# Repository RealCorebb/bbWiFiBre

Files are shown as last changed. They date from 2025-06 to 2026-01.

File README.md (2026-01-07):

# bbWiFibre [English](https://github.com/RealCorebb/bbWiFiBre/blob/main/README_EN.md "English")

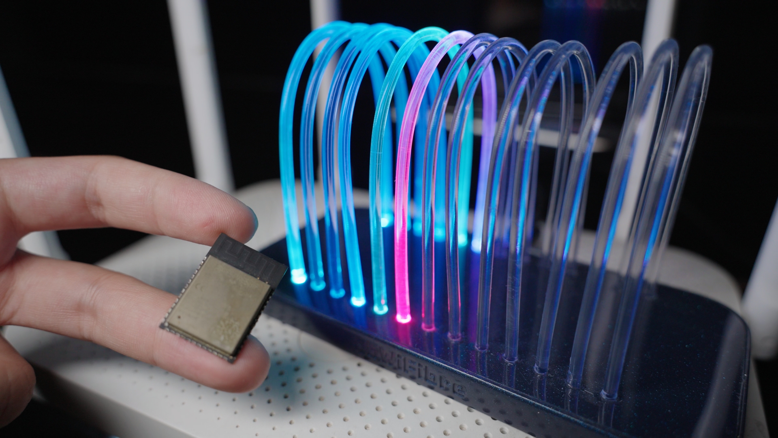
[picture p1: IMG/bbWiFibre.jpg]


## 能看见 WiFi 信号的氛围灯

电脑、路由器网口上闪烁的小灯大家都不陌生，看上去像是在乱闪，没人太在意。那无线的 Wi-Fi 网络，能不能也做一个这种“信号灯”呢？于是我 DIY 了一个 Wi-Fi 嗅探器，并将捕捉到的数据通过代码和算法进行可视化，变成了一个可以实时探测 Wi-Fi 信号的氛围灯。

😄[爱发电](https://afdian.com/a/kuruibb "爱发电") (已更新此图文教程）  
🧵[Threads](https://www.threads.net/@coreoobb "@coreoobb") @coreoobb  
🐧QQ 群（仅供交流，人满请加Discord）：647186542  
😈Discord 频道：[加入](https://discord.gg/gvbcCtdQrk "加入")   
▶️ 本期视频(Video): [Youtube](https://youtu.be/fgVX8Ttq5zc "Youtube") | [ Bilibili](https://www.bilibili.com/video/BV1DB8xz7E7a " Bilibili")

# 禁止搬运到 Gitee

Designed By Corebb With Love From bbRealm!

# 目录结构：

**Arduino** Arduino 主程序，烧录到 ESP32 中  
**PCB** PCB 原理图、Gerber 制板文件、BOM  
**CAD** 3D模型、DXF切割图纸  
**test** Arduino 测试程序，作为嗅探器输出调试信息  

# 参考资料：

灵感来源 
[Network activity visualizer by Alex Chang](https://www.hackster.io/alex_chang/network-activity-visualizer-e86cec)

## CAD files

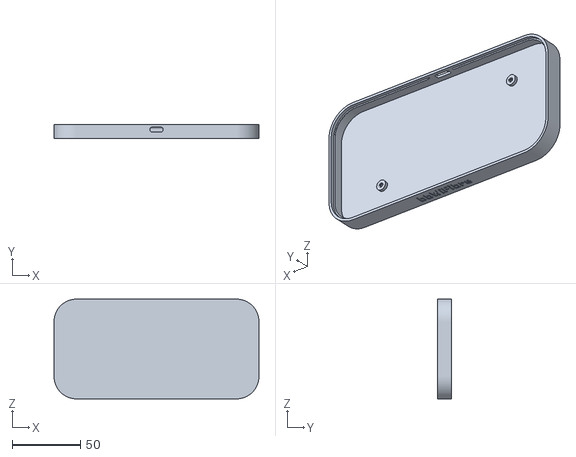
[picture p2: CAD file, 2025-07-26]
CAD/Shell.stl
150.0 x 10.5 x 73.0

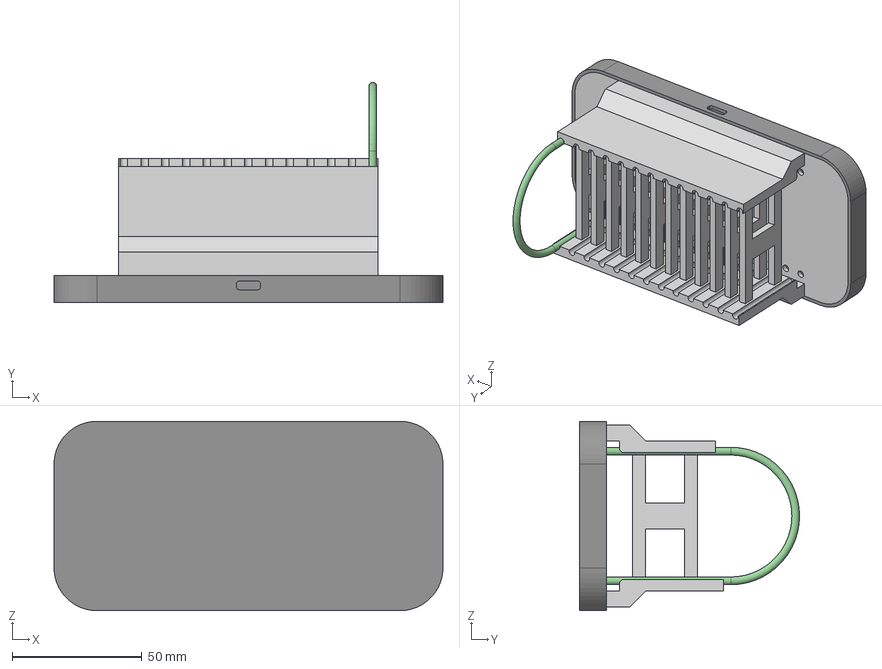
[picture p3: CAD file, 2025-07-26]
CAD/bbWiFibre v16.step
150.0 x 84.9 x 73.0 mm
Fibre
Cover

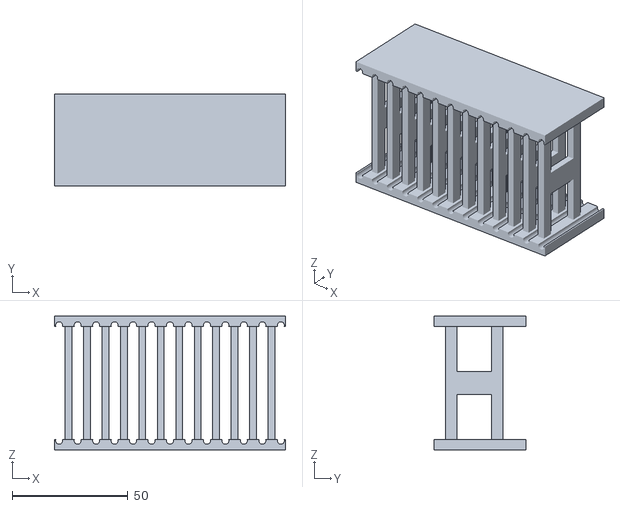
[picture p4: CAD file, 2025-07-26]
CAD/Fixture.stl
100.0 x 40.0 x 58.0

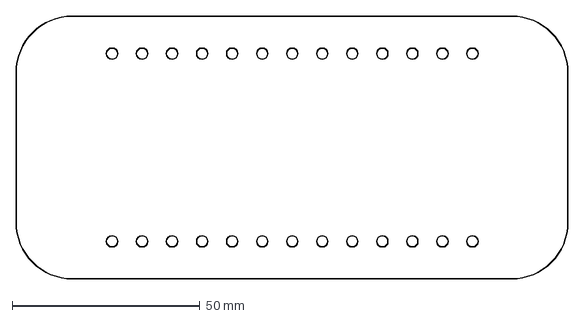
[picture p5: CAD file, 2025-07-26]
CAD/Cover.dxf
147.0 x 70.0 mm

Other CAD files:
CAD/mold_A.step
CAD/mold_B.step

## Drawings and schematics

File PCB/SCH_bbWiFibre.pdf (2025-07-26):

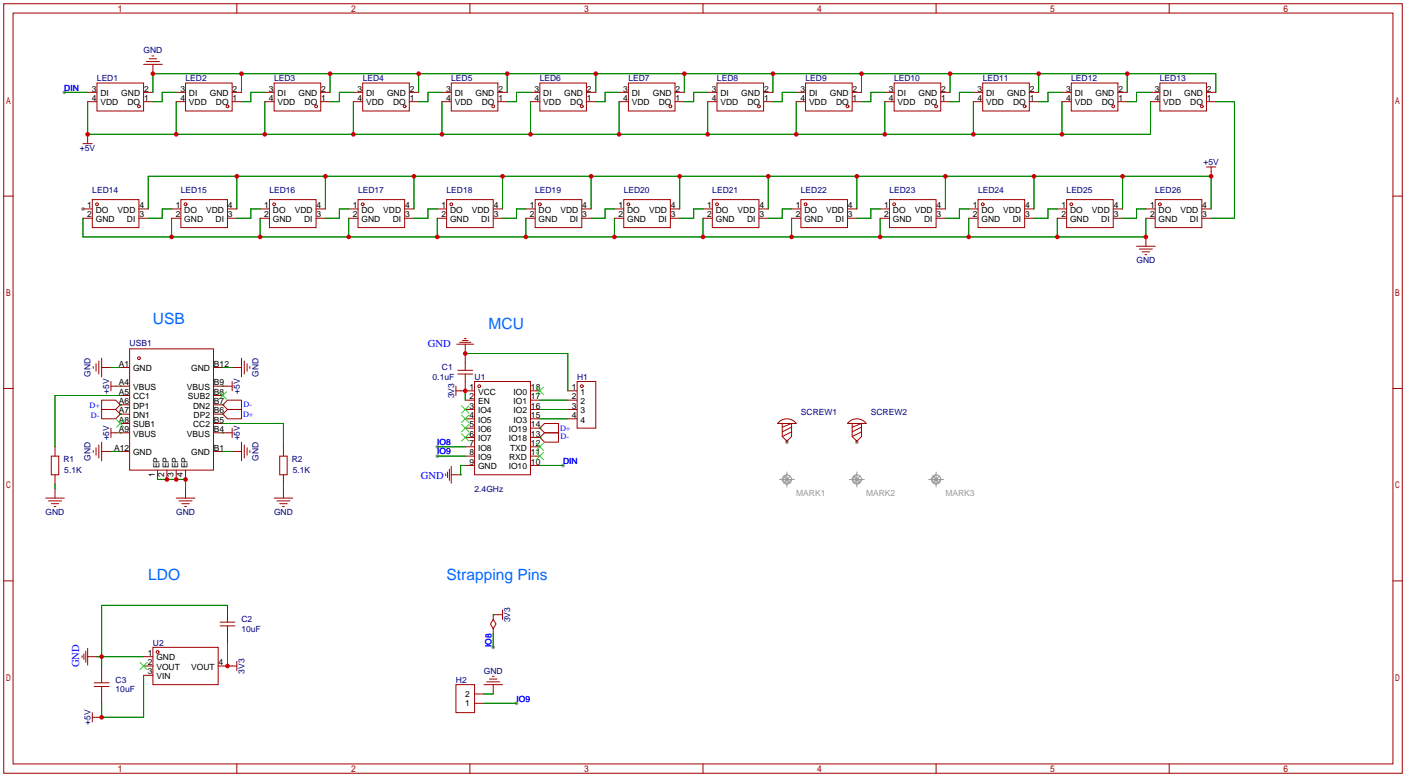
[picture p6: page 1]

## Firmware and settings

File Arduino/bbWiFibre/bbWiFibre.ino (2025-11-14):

#include "bbWiFiBre.h"
#include <Preferences.h>
#include <BLEDevice.h>
#include <BLEServer.h>
#include <BLEUtils.h>
#include <BLE2902.h>

// BLE UUIDs
#define SERVICE_UUID        "12345678-1234-1234-1234-123456789abc"
#define CHARACTERISTIC_UUID "87654321-4321-4321-4321-cba987654321"

// BLE objects
BLEServer* pServer = NULL;
BLECharacteristic* pCharacteristic = NULL;
bool deviceConnected = false;
bool oldDeviceConnected = false;

// Mode definitions
#define MODE_MONITOR_AP 1
#define MODE_SCAN_CHANNEL 2
#define MODE_RSSI 3

// Global variables
Adafruit_NeoPixel strip(NUM_LEDS, LED_PIN, NEO_GRB + NEO_KHZ800);
volatile int currentMode = MODE_MONITOR_AP;
TaskHandle_t modeTaskHandle = NULL;
TaskHandle_t channelTaskHandle = NULL;  // Added for mode2's second task
int currentBrightness = 200; // Default brightness

Preferences preferences;

// Forward declaration
void processSerialCommand(String command);

class MyServerCallbacks: public BLEServerCallbacks {
    void onConnect(BLEServer* pServer) {
        deviceConnected = true;
        Serial.println("BLE Client connected");
    };

    void onDisconnect(BLEServer* pServer) {
        deviceConnected = false;
        Serial.println("BLE Client disconnected");
    }
};

class MyCallbacks: public BLECharacteristicCallbacks {
    void onWrite(BLECharacteristic *pCharacteristic) {
        String rxValue = pCharacteristic->getValue();
        if (rxValue.length() > 0) {
            Serial.println("BLE Command received: " + rxValue);
            processSerialCommand(rxValue);
        }
    }
};

void initBLE() {
    BLEDevice::init("bbWiFibre-BLE");
    pServer = BLEDevice::createServer();
    pServer->setCallbacks(new MyServerCallbacks());

    BLEService *pService = pServer->createService(SERVICE_UUID);

    pCharacteristic = pService->createCharacteristic(
                         CHARACTERISTIC_UUID,
                         BLECharacteristic::PROPERTY_READ   |
                         BLECharacteristic::PROPERTY_WRITE  |
                         BLECharacteristic::PROPERTY_NOTIFY |
                         BLECharacteristic::PROPERTY_INDICATE
                       );

    pCharacteristic->setCallbacks(new MyCallbacks());
    pCharacteristic->addDescriptor(new BLE2902());

    pService->start();
    
    BLEAdvertising *pAdvertising = BLEDevice::getAdvertising();
    pAdvertising->addServiceUUID(SERVICE_UUID);
    pAdvertising->setScanResponse(false);
    pAdvertising->setMinPreferred(0x0);  // set value to 0x00 to not advertise this parameter
    BLEDevice::startAdvertising();
    
    Serial.println("BLE service started, waiting for connections...");
}

void sendBLEMessage(String message) {
    if (deviceConnected && pCharacteristic) {
        pCharacteristic->setValue(message.c_str());
        pCharacteristic->notify();
    }
}

void saveCurrentMode() {
    preferences.begin("appState", false);
    preferences.putInt("lastMode", currentMode);
    preferences.end();
    Serial.printf("Saved mode %d to NVS.\n", currentMode);
}

void saveBrightness() {
    preferences.begin("appState", false);
    preferences.putInt("brightness", currentBrightness);
    preferences.end();
    Serial.printf("Saved brightness %d to NVS.\n", currentBrightness);
}

void loadBrightness() {
    preferences.begin("appState", true); // Read-only
    currentBrightness = preferences.getInt("brightness", 200); // Default to 200 if not found
    preferences.end();
    Serial.printf("Loaded brightness %d from NVS.\n", currentBrightness);
    
    // Apply the loaded brightness
    strip.setBrightness(currentBrightness);
    strip.show();
}

void setBrightness(int brightness) {
    if (brightness >= 10 && brightness <= 255) {
        currentBrightness = brightness;
        strip.setBrightness(currentBrightness);
        strip.show();
        saveBrightness();
        Serial.printf("Brightness set to: %d\n", currentBrightness);
    } else {
        Serial.printf("Invalid brightness value: %d. Must be between 10-255.\n", brightness);
    }
}

void stopCurrentMode() {
    Serial.println("Stopping current mode...");
    esp_wifi_set_promiscuous(false);
    esp_wifi_set_promiscuous_rx_cb(NULL);
    Serial.println("WiFi promiscuous mode stopped.");

    int modeToClean = currentMode; // Capture the mode that is being stopped

    if (modeTaskHandle != NULL) {
        Serial.printf("Deleting modeTaskHandle (was for mode %d)\n", modeToClean);
        vTaskDelete(modeTaskHandle);
        modeTaskHandle = NULL;
    }
    if (channelTaskHandle != NULL) { // Specific to MODE_SCAN_CHANNEL
        Serial.printf("Deleting channelTaskHandle (was for mode %d)\n", modeToClean);
        vTaskDelete(channelTaskHandle);
        channelTaskHandle = NULL;
    }

    Serial.println("Delaying for task cleanup (500ms)...");
    vTaskDelay(pdMS_TO_TICKS(250));

    strip.clear();
    strip.show();
    Serial.println("LEDs cleared.");

    if (modeToClean == MODE_MONITOR_AP && deviceDataMutex != NULL) {
        Serial.println("Deleting deviceDataMutex");
        vSemaphoreDelete(deviceDataMutex);
        deviceDataMutex = NULL;
    } else if (modeToClean == MODE_SCAN_CHANNEL && xSemaphore != NULL) {
        Serial.println("Deleting xSemaphore for channel scan");
        vSemaphoreDelete(xSemaphore);
        xSemaphore = NULL;
    } else if (modeToClean == MODE_RSSI && g_rssiDataMutex != NULL) {
        Serial.println("Deleting g_rssiDataMutex");
        vSemaphoreDelete(g_rssiDataMutex);
        g_rssiDataMutex = NULL;
    }
    Serial.println("Semaphores deleted (if any). Mode stopping sequence complete.");
}

void startMonitorAPMode() {
    Serial.println("Initializing Monitor AP Mode...");
    stopCurrentMode(); // Ensure any previous mode is fully stopped
    currentMode = MODE_MONITOR_AP;

    deviceDataMutex = xSemaphoreCreateMutex();
    if (deviceDataMutex == NULL) {
        Serial.println("Failed to create deviceDataMutex");
        return;
    }

    g_esp_boot_time_ms = millis();
    g_intruder_detection_armed = false;
    g_intruder_alert_active = false;
    for (int i = 0; i < MAX_CLIENT_DEVICES; i++) {
        trackedClientDevices[i].isActive = false;
        trackedClientDevices[i].activityScoreToAP = 0;
        trackedClientDevices[i].activityScoreFromAP = 0;
        memset(trackedClientDevices[i].mac, 0, 6);
    }

    esp_err_t err = esp_wifi_set_promiscuous(true);
    if (err != ESP_OK) { Serial.printf("Failed to set promiscuous mode: %s\n", esp_err_to_name(err)); vSemaphoreDelete(deviceDataMutex); deviceDataMutex = NULL; return; }
    err = esp_wifi_set_channel(WIFI_CHANNEL, WIFI_SECOND_CHAN_NONE);
    if (err != ESP_OK) { Serial.printf("Failed to set channel: %s\n", esp_err_to_name(err)); vSemaphoreDelete(deviceDataMutex); deviceDataMutex = NULL; return; }
    err = esp_wifi_set_promiscuous_rx_cb(wifi_sniffer_packet_handler);
    if (err != ESP_OK) { Serial.printf("Failed to set callback: %s\n", esp_err_to_name(err)); vSemaphoreDelete(deviceDataMutex); deviceDataMutex = NULL; return; }

    BaseType_t xReturned = xTaskCreatePinnedToCore(led_update_task, "LEDUpdateTask", 4096, NULL, 2, &modeTaskHandle, tskNO_AFFINITY);
    if (xReturned != pdPASS) {
        Serial.println("Failed to create LED update task for Monitor AP");
        vSemaphoreDelete(deviceDataMutex); deviceDataMutex = NULL;
        return;
    }

    Serial.println("Monitor AP Mode Started Successfully");
    Serial.printf("Monitoring on Channel: %d\n", WIFI_CHANNEL);
    saveCurrentMode();
}

void startScanChannelMode() {
    Serial.println("Initializing Channel Scan Mode...");
    stopCurrentMode();
    currentMode = MODE_SCAN_CHANNEL;

    xSemaphore = xSemaphoreCreateMutex();
    if (xSemaphore == NULL) {
        Serial.println("Failed to create xSemaphore for Channel Scan");
        return;
    }

    currentScanningChannel = 1;
    for (int i = 0; i < CHANNELS; i++) {
        pendingActivityIncrements[i] = 0;
        channelActivity[i] = 0;
        channelBrightness[i] = 1.0f;
        pendingColorForDelayedLed[i] = OFF_COLOR;
        framesToDelayForLed[i] = 0;
    }

    esp_err_t err = esp_wifi_set_promiscuous(true);
    if (err != ESP_OK) { Serial.printf("Failed to set promiscuous mode: %s\n", esp_err_to_name(err)); vSemaphoreDelete(xSemaphore); xSemaphore = NULL; return; }
    err = esp_wifi_set_promiscuous_rx_cb(onWiFiPacket);
    if (err != ESP_OK) { Serial.printf("Failed to set callback: %s\n", esp_err_to_name(err)); vSemaphoreDelete(xSemaphore); xSemaphore = NULL; return; }
    err = esp_wifi_set_channel(currentScanningChannel, WIFI_SECOND_CHAN_NONE);
    if (err != ESP_OK) { Serial.printf("Failed to set channel: %s\n", esp_err_to_name(err)); vSemaphoreDelete(xSemaphore); xSemaphore = NULL; return; }

    BaseType_t xReturnedLed = xTaskCreatePinnedToCore(LEDUpdateTask, "LEDTask", 4096, NULL, 2, &modeTaskHandle, tskNO_AFFINITY);
    if (xReturnedLed != pdPASS) {
        Serial.println("Failed to create LED update task for Channel Scan");
        vSemaphoreDelete(xSemaphore); xSemaphore = NULL;
        return;
    }

    BaseType_t xReturnedChannel = xTaskCreatePinnedToCore(ChannelTask, "ChannelTask", 4096, NULL, 1, &channelTaskHandle, tskNO_AFFINITY);
    if (xReturnedChannel != pdPASS) {
        Serial.println("Failed to create channel task for Channel Scan");
        if(modeTaskHandle != NULL) vTaskDelete(modeTaskHandle); modeTaskHandle = NULL;
        vSemaphoreDelete(xSemaphore); xSemaphore = NULL;
        return;
    }

    Serial.println("Channel Scan Mode Started Successfully");
    saveCurrentMode();
}

void startRSSIMode() {
    Serial.println("Initializing RSSI Mode...");
    stopCurrentMode();
    currentMode = MODE_RSSI;

    g_rssiDataMutex = xSemaphoreCreateMutex();
    if (g_rssiDataMutex == NULL) {
        Serial.println("Failed to create RSSI mutex");
        return;
    }

    g_latestRSSI = -100;
    g_routerIsVisible = false;
    g_smoothedRSSI = -100.0f; // Assuming float

    BaseType_t xReturned = xTaskCreatePinnedToCore(RSSIUpdateTask, "RSSITask", 4096, NULL, 2, &modeTaskHandle, tskNO_AFFINITY);
    if (xReturned != pdPASS) {
        Serial.println("Failed to create RSSI update task");
        vSemaphoreDelete(g_rssiDataMutex); g_rssiDataMutex = NULL;
        return;
    }

    Serial.println("RSSI Mode Started Successfully");
    saveCurrentMode();
}

void processSerialCommand(String command) {
    command.trim();

    if (command == "mode1") {
        if (currentMode != MODE_MONITOR_AP) {
            startMonitorAPMode();
        } else {
            Serial.println("Already in Monitor AP Mode");
            sendBLEMessage("Already in Monitor AP Mode");
        }
    } else if (command == "mode2") {
        if (currentMode != MODE_SCAN_CHANNEL) {
            startScanChannelMode();
        } else {
            Serial.println("Already in Channel Scan Mode");
            sendBLEMessage("Already in Channel Scan Mode");
        }
    } else if (command == "mode3") {
        if (currentMode != MODE_RSSI) {
            startRSSIMode();
        } else {
            Serial.println("Already in RSSI Mode");
            sendBLEMessage("Already in RSSI Mode");
        }
    } else if (command.startsWith("brightness:")) {
        int brightness = command.substring(11).toInt();
        setBrightness(brightness);
    } else if (command == "status") {
        // Additional command to check current settings
        String statusMsg = "Current Mode: " + String(currentMode) + ", Brightness: " + String(currentBrightness);
        Serial.println(statusMsg);
        sendBLEMessage(statusMsg);
    } else {
        String helpMsg = "Invalid command. Use 'mode1', 'mode2', 'mode3', 'brightness:XXX', or 'status'";
        Serial.println(helpMsg);
        sendBLEMessage(helpMsg);
    }
}

void serialCommandTask(void* parameter) {
    while (true) {
        // Check USB Serial
        if (Serial.available()) {
            String command = Serial.readStringUntil('\n');
            processSerialCommand(command);
            vTaskDelay(pdMS_TO_TICKS(50));
        }
        
        vTaskDelay(pdMS_TO_TICKS(100));
    }
}

void bleConnectionTask(void* parameter) {
    while (true) {
        // Handle BLE disconnection/reconnection
        if (!deviceConnected && oldDeviceConnected) {
            vTaskDelay(pdMS_TO_TICKS(500)); // give the bluetooth stack the chance to get things ready
            pServer->startAdvertising(); // restart advertising
            Serial.println("Start advertising");
            oldDeviceConnected = deviceConnected;
        }
        
        // Handle new BLE connection
        if (deviceConnected && !oldDeviceConnected) {
            oldDeviceConnected = deviceConnected;
        }
        
        vTaskDelay(pdMS_TO_TICKS(1000));
    }
}

void setup() {
    Serial.begin(115200);
    //while (!Serial) { delay(10); }

    Serial.println("bbWiFiBre - Multi-mode WiFi Monitor with BLE");
    Serial.println("Commands:");
    Serial.println("  mode1 - Monitor AP Mode");
    Serial.println("  mode2 - Channel Scan Mode");
    Serial.println("  mode3 - RSSI Mode");
    Serial.println("  brightness:XXX - Set brightness (10-255)");
    Serial.println("  status - Show current settings");

    // Initialize BLE
    initBLE();

    strip.begin();
    
    // Load saved brightness before setting it
    loadBrightness();

    WiFi.mode(WIFI_STA); // Initialize WiFi stack
    WiFi.disconnect();   // Disconnect from any previous network

    preferences.begin("appState", true); // Read-only to check
    int savedMode = preferences.getInt("lastMode", MODE_MONITOR_AP);
    preferences.end();
    Serial.printf("Loaded mode %d from NVS.\n", savedMode);

    // Create a task for Serial command monitoring
    xTaskCreate(serialCommandTask, "SerialCommand", 4096, NULL, 1, NULL);
    
    // Create a task for BLE connection management
    xTaskCreate(bleConnectionTask, "BLEConnection", 4096, NULL, 1, NULL);

    delay(1000); // Allow serial task to initialize, etc.

    if (savedMode == MODE_MONITOR_AP) {
        startMonitorAPMode();
    } else if (savedMode == MODE_SCAN_CHANNEL) {
        startScanChannelMode();
    } else if (savedMode == MODE_RSSI) {
        startRSSIMode();
    } else {
        Serial.println("Invalid mode from NVS, defaulting to Monitor AP Mode.");
        startMonitorAPMode();
    }
}

void loop() {
    // Main loop is not used as we're using FreeRTOS tasks
    vTaskDelay(pdMS_TO_TICKS(1000));
}

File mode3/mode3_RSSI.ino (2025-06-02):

#include <WiFi.h>
#include <esp_wifi.h> // For esp_wifi_scan_start
#include <Adafruit_NeoPixel.h>
#include <string.h>   // For memcmp
#include <math.h>     // For fmin, fmax, sinf

// --- WiFi Configuration ---
// << (!!! REQUIRED !!!) REPLACE WITH YOUR ROUTER'S ACTUAL MAC ADDRESS >>
const uint8_t TARGET_ROUTER_MAC[6] = {0xAA, 0xBB, 0xCC, 0xDD, 0xEE, 0xFF};
// << (RECOMMENDED) SET YOUR ROUTER'S 2.4GHz CHANNEL (1-13), OR 0 TO SCAN ALL CHANNELS >>
const uint8_t TARGET_ROUTER_CHANNEL = 0; // 0 scans all, 1-13 targets a specific channel

// --- LED Configuration ---
#define LED_PIN 10
#define NUM_RSSI_SLOTS 13 // We have 13 "columns" or slots to display RSSI
#define NUM_LEDS (NUM_RSSI_SLOTS * 2) // Each slot uses 2 LEDs (one per row)
const int GLOBAL_LED_BRIGHTNESS = 90; // Global brightness for the strip (0-255)

// --- RSSI Mapping & Visualization Tuning ---
const int RSSI_MIN_THRESHOLD = -90; // RSSI value considered the weakest signal for our scale
const int RSSI_MAX_THRESHOLD = -35; // RSSI value considered the strongest signal for our scale
const float RSSI_SMOOTHING_FACTOR = 0.4f; // For EMA filter (0.0 to 1.0, higher = more smoothing but slower reaction)

// Color Mapping (Hue values for Adafruit_NeoPixel::ColorHSV which uses 0-65535 for hue)
const uint16_t HUE_WEAK_SIGNAL = 0;       // Red
const uint16_t HUE_STRONG_SIGNAL = 21845; // Green (approx 120 degrees on a 360 scale)

// --- Animation Tuning ---
const TickType_t LED_UPDATE_INTERVAL_MS = 40; // Approx 25 FPS for LED animations
const unsigned long WIFI_SCAN_INTERVAL_MS = 2500; // How often to initiate a new WiFi scan

// Breathing effect for the lit RSSI bar
const bool ENABLE_RSSI_BAR_BREATHING = true;
const float RSSI_BAR_BREATH_SPEED = 0.8f;     // Speed of brightness oscillation (cycles per second)
const uint8_t RSSI_BAR_BREATH_MIN_V = 180;    // Min HSV Value (brightness) for breathing (0-255)
const uint8_t RSSI_BAR_BREATH_MAX_V = 255;    // Max HSV Value (brightness) for breathing

// Effect for when the target router is NOT found
const bool ENABLE_NOT_FOUND_EFFECT = true;
const char* NOT_FOUND_EFFECT_TYPE = "PULSE_ALL_RED"; // "PULSE_ALL_RED" or "CHASE_LIGHT" (Chase not implemented here for brevity)
const uint8_t NOT_FOUND_PULSE_MIN_V = 10;
const uint8_t NOT_FOUND_PULSE_MAX_V = 70;
const float NOT_FOUND_PULSE_SPEED = 0.6f;

// Color for unlit slots within the RSSI bar range (when router IS found but signal isn't max)
const uint8_t UNLIT_RSSI_SLOT_R = 0;
const uint8_t UNLIT_RSSI_SLOT_G = 5;
const uint8_t UNLIT_RSSI_SLOT_B = 10; // Very dim deep blue/teal

// --- Global Variables ---
Adafruit_NeoPixel strip(NUM_LEDS, LED_PIN, NEO_GRB + NEO_KHZ800);

volatile int g_latestRSSI = RSSI_MIN_THRESHOLD - 1; // Initial "not found" state
volatile bool g_routerIsVisible = false;
float g_smoothedRSSI = RSSI_MIN_THRESHOLD - 1;
SemaphoreHandle_t g_rssiDataMutex;

unsigned long g_lastScanInitiationTime = 0;
bool g_scanIsOngoing = false;

// --- Function Prototypes ---
void process_wifi_scan_results(int num_networks_found);
void update_router_visibility_status(bool found, int rssi_value);
uint32_t get_rssi_color_hsv(float current_rssi, uint8_t hsv_value);


// --- Setup Function ---
void setup() {
    Serial.begin(115200);
    while (!Serial) { delay(10); }
    Serial.println("ESP32 WiFi RSSI Visualizer Starting...");

    strip.begin();
    strip.setBrightness(GLOBAL_LED_BRIGHTNESS);
    strip.show(); // Initialize all LEDs to off

    g_rssiDataMutex = xSemaphoreCreateMutex();
    if (g_rssiDataMutex == NULL) {
        Serial.println("Error: Mutex creation failed!");
        while (1) { delay(1000); }
    }

    WiFi.mode(WIFI_STA);
    WiFi.disconnect(); // Ensure we are not connected to any network

    Serial.print("Target Router MAC: ");
    for(int i=0; i<6; ++i) { Serial.printf("%02X", TARGET_ROUTER_MAC[i]); if(i<5) Serial.print(":"); }
    Serial.println();
    Serial.printf("Target Router Channel (0 for all): %d\n", TARGET_ROUTER_CHANNEL);

    // Create LED update task
    xTaskCreatePinnedToCore(
        led_update_task,
        "LEDUpdateTask",
        4096,
        NULL,
        2,
        NULL,
        tskNO_AFFINITY);
}

// --- Main Loop (Handles WiFi Scanning Cycle) ---
void loop() {
    if (!g_scanIsOngoing && (millis() - g_lastScanInitiationTime > WIFI_SCAN_INTERVAL_MS)) {
        Serial.println("Initiating WiFi scan...");
        // Asynchronous scan. Args: (async, show_hidden, passive, max_ms_per_chan, channel)
        WiFi.scanNetworks(true, false, false, 250, TARGET_ROUTER_CHANNEL);
        g_scanIsOngoing = true;
        g_lastScanInitiationTime = millis();
    }

    if (g_scanIsOngoing) {
        int16_t scan_result = WiFi.scanComplete(); // Returns num networks, -1 (WIFI_SCAN_RUNNING), or -2 (WIFI_SCAN_FAILED)
        if (scan_result >= 0) { // Scan finished successfully
            Serial.printf("Scan complete. Networks found: %d\n", scan_result);
            process_wifi_scan_results(scan_result);
            WiFi.scanDelete(); // Important: Free the memory from scan results
            g_scanIsOngoing = false;
        } else if (scan_result == WIFI_SCAN_FAILED) {
            Serial.println("WiFi scan failed.");
            update_router_visibility_status(false, RSSI_MIN_THRESHOLD - 1);
            g_scanIsOngoing = false;
        }
        // If WIFI_SCAN_RUNNING, do nothing and wait.
    }
    vTaskDelay(pdMS_TO_TICKS(100)); // Small delay to prevent loop from running too fast
}

// --- Process WiFi Scan Results ---
void process_wifi_scan_results(int num_networks_found) {
    bool found_this_scan = false;
    int rssi_this_scan = RSSI_MIN_THRESHOLD - 1;

    for (int i = 0; i < num_networks_found; ++i) {
        if (memcmp(WiFi.BSSID(i), TARGET_ROUTER_MAC, 6) == 0) {
            rssi_this_scan = WiFi.RSSI(i);
            found_this_scan = true;
            Serial.printf("Target router '%s' FOUND with RSSI: %d dBm\n", WiFi.SSID(i).c_str(), rssi_this_scan);
            break;
        }
    }
    if (!found_this_scan) {
        Serial.println("Target router NOT found in this scan.");
    }
    update_router_visibility_status(found_this_scan, rssi_this_scan);
}

// --- Update Global Router Status (Thread-Safe) ---
void update_router_visibility_status(bool found, int rssi_value) {
    if (xSemaphoreTake(g_rssiDataMutex, portMAX_DELAY) == pdTRUE) {
        g_routerIsVisible = found;
        g_latestRSSI = found ? rssi_value : (RSSI_MIN_THRESHOLD - 1); // Use out-of-range if not found
        xSemaphoreGive(g_rssiDataMutex);
    }
}
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

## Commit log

2025-05-28 tuning for empty slots
2025-06-03 make it available to switch mode / compile
2025-06-04 Fix switch mode freezing
    [bbWiFibre.h, bbWiFibre.ino, mode3_RSSI.ino]
2025-07-26 CAD & PCB
    [Cover.dxf, Fixture.stl, Shell.stl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]
